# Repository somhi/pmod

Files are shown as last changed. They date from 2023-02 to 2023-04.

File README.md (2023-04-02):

# PMOD / USB3 adapters

This repository is home of simple adapters between PMOD / USB3 and other connectors.

* PMOD-USB3 is a passive adapter between PMOD and USB3 (see SNAC adapters used in MiSTer project).
* PS2-UART-USB3 is a passive adapter between USB3 and PS2 connector (mouse+keyboard). It also offers an UART header (Rx/Tx).

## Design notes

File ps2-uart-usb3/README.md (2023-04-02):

# USB3 to PS2/UART adapter

PS2-UART-USB3 is a passive adapter between USB3 and PS2 connector (mouse+keyboard). It also offers an UART header (Rx/Tx/GND). 

**STATUS**: working Ok. See testing and improvement notes below.

See correspondence of pins in [schematic](pmod.pdf). 

PS2 connector has all signal pins connected so a splitter cable can be used to connect a PS2 keyboard and mouse.

JP1 header is for selecting power supply of PS2 connector. Three options are possible:

* 5V: Place a jumper between VBUS and central pin
* External power supply can also be connected to the central pin and GND.
* ~~3V3: Place a jumper between 3V3 and central pin. For this is required a MiSTer Analog IO version with a jumper that connects 3V3 to pin 9 of USB3~~.  [CAUTION: this is not possible when using a male male USB3 cable as the pin 9 is connected to pin 5 at the other end of cable]

**NOTES ABOUT USB3 CABLES**

* male male cable is crossover cable, meaning that Rx- is connected to Tx- and Rx+ to Tx+

* female male cable is straight cable, meaning all pins have exact correspondence in each side of cable (Rx- with Rx-, ...)

**SETUP IN MISTER DE10-nano FPGA**

* Connect  an [SNAC level shifter adapter](https://manuferhi.com/p/snac-adapter-for-mister) to the user IO port of MiSTer Analog addon

* Connect a male male USB3 cable between the SNAC adapter and the USB3 to PS2 adapter

* Connect a [PS2 splitter cable](https://es.aliexpress.com/item/32827138560.html) if you intend to use keyboard and mouse simultaneously.

**TODO & IMPROVEMENTS**

* Make a male USB3 version with voltage protections so the SNAC adapter and male male cable would be unnecessary
* Shield pins of PS2 connector are not connected to GND
* 3V3 silkscreen NOTE at pcb back "3V3 from MiSTer analog IO with user IO jumper placed"

**TESTING**

* Tested using PMOD-USB3 adapter: UART, keyboard and mouse works well, with 3V3 without SNAC adapter, or with 5V and SNAC level shifter adapter.  This means in MiSTer should work.

  NOTE: Code in FPGA side need to take into account the crossover signals of the male to male cable.

* Tested from USB3 port of Deca cape: Keyboard not working good with the integrated level shifter of Deca cape.

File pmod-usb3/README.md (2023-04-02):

# PMOD to USB3 adapter

PMOD-USB3 is a passive adapter between PMOD and USB3. Only 7 pins are wired as is the maximum of USB3. 

**STATUS**: tested with a GEN SMS SNAC with a gamepad working well with 3V3

See correspondence of pins in [schematic](pmod.pdf). 

PMOD only outputs 3V3. 

JP1 header is for detaching power supply pin from both connectors, as PMOD is 3V3 and VBUS is usually 5V. 

JP1 header header has three pins: 3V3 from PMOD, VBUS from USB3 and GND. 

VBUS is the power supply to whatever is connected to the SNAC adapter. 

Different power supply options:

* Placing a jumper between 3V3 and VBUS (will not work on all gamepads)

* Other option is to connect 5V wire from FPGA to VBUS pin   (note that this will require to use a SNAC level shifter in between for protecting 3V3 GPIO)

* Third option would be to get 5V from external power supply so you will need to connect two wires: VBUS to 5V and GND (SNAC level shifter required also).

**PLEASE MAKE SURE NOT TO PLACE A JUMPER EVER BETWEEN VBUS AND GND PINS. I'm not responsible for what could happen.**

**NOTES ABOUT USB3 CABLES**

* male male cable is crossover cable, meaning that Rx- is connected to Tx- and Rx+ to Tx+

* female male cable is straight cable, meaning all pins have exact correspondence in each side of cable (Rx- with Rx-, ...)

**TODO**

* move GND pin to avoid user placing a jumper which will short GND and VBUS

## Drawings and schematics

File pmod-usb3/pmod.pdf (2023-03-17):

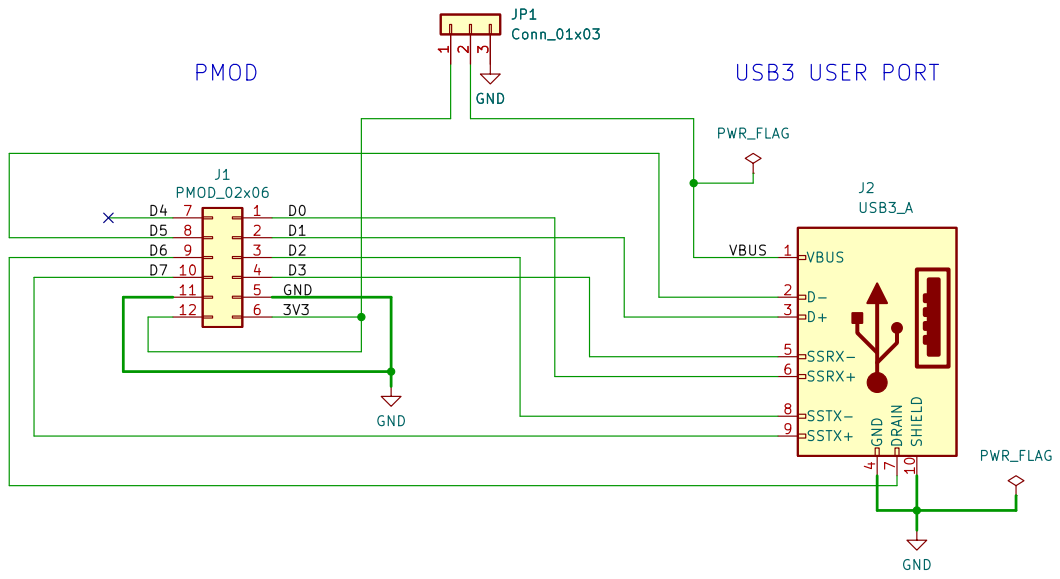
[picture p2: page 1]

10 | 4
11 | 5
12 | 6

Id: 1/1 Title: Pmod / USB3 adapters

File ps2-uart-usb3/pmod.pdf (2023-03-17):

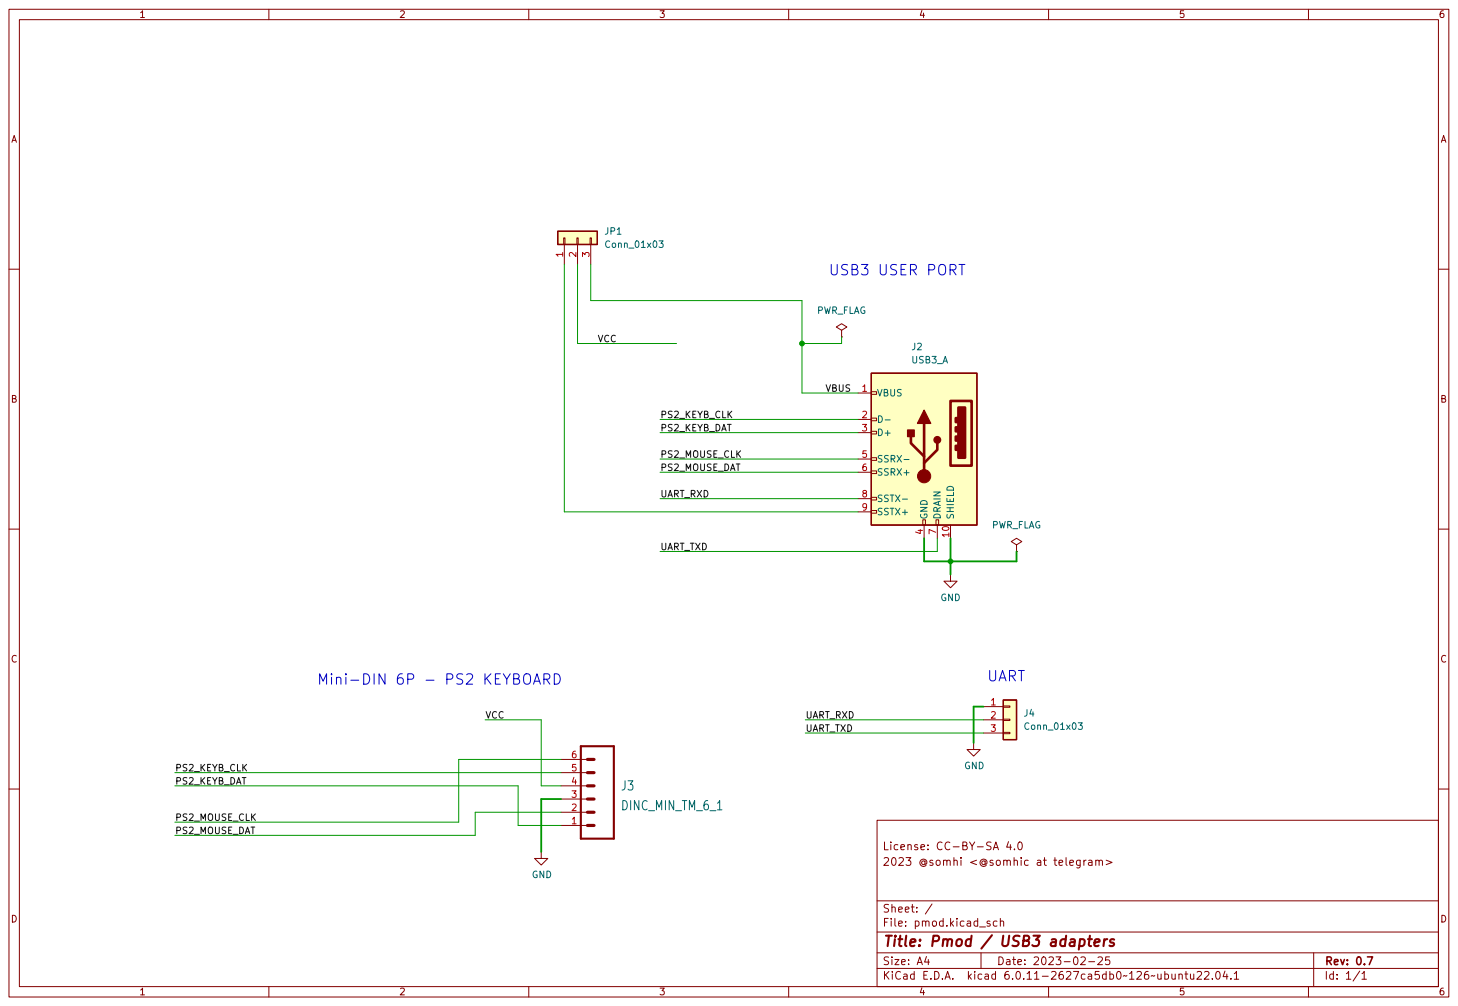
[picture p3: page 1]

Id: 1/1 Title: Pmod / USB3 adapters

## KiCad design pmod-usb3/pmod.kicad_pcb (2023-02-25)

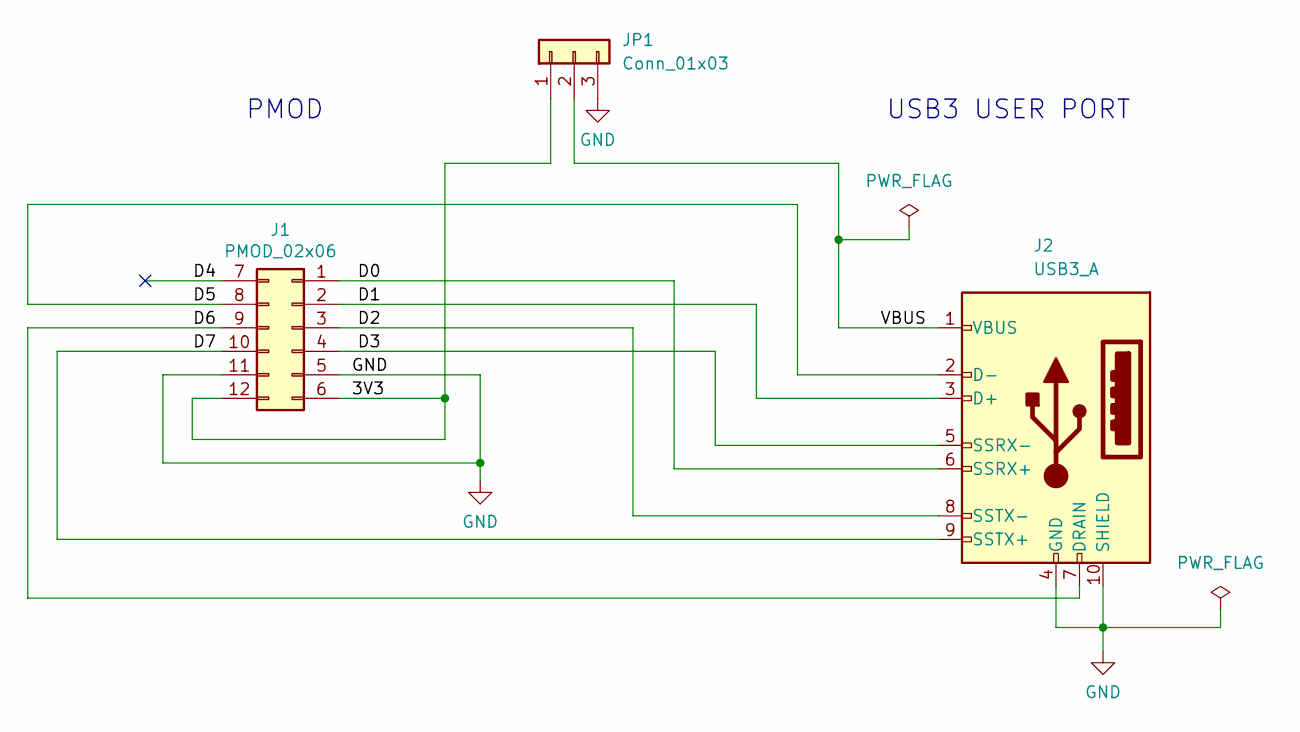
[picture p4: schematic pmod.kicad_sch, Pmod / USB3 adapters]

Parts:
J1: PMOD_02x06; PMODHeader_2x06_P2.54mm_Horizontal
J2: USB3_A; USB-3.0-TH_C69073
JP1: Conn_01x03; PinHeader_1x03_P2.54mm_Vertical

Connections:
/3V3: J1.6, J1.12, JP1.1
/D0: J1.1, J2.6 (SSRX+)
/D1: J1.2, J2.3 (D+)
/D2: J1.3, J2.8 (SSTX-)
/D3: J1.4, J2.5 (SSRX-)
/D4: J1.7
/D5: J1.8, J2.2 (D-)
/D6: J1.9, J2.7 (DRAIN)
/D7: J1.10, J2.9 (SSTX+)
/VBUS: J2.1 (VBUS), JP1.2
GND: J1.5, J1.11, J2.4 (GND), J2.10 (SHIELD), JP1.3

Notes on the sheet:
PMOD
USB3 USER PORT

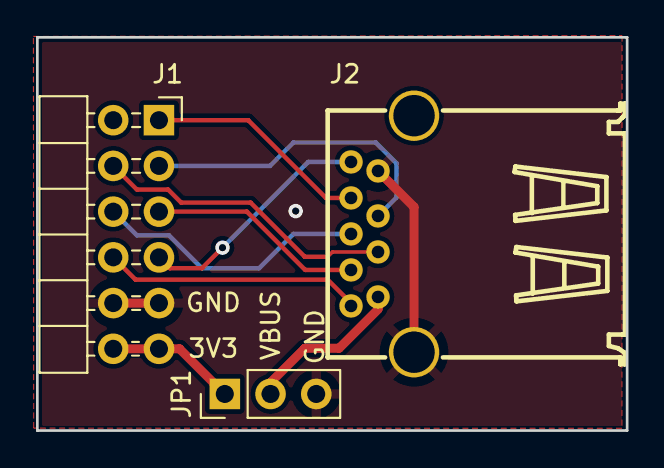
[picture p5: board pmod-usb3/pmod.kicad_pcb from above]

Board: 2 copper layers, 32.8 x 21.8 mm, 3 parts (0 on the bottom side), 10 nets.

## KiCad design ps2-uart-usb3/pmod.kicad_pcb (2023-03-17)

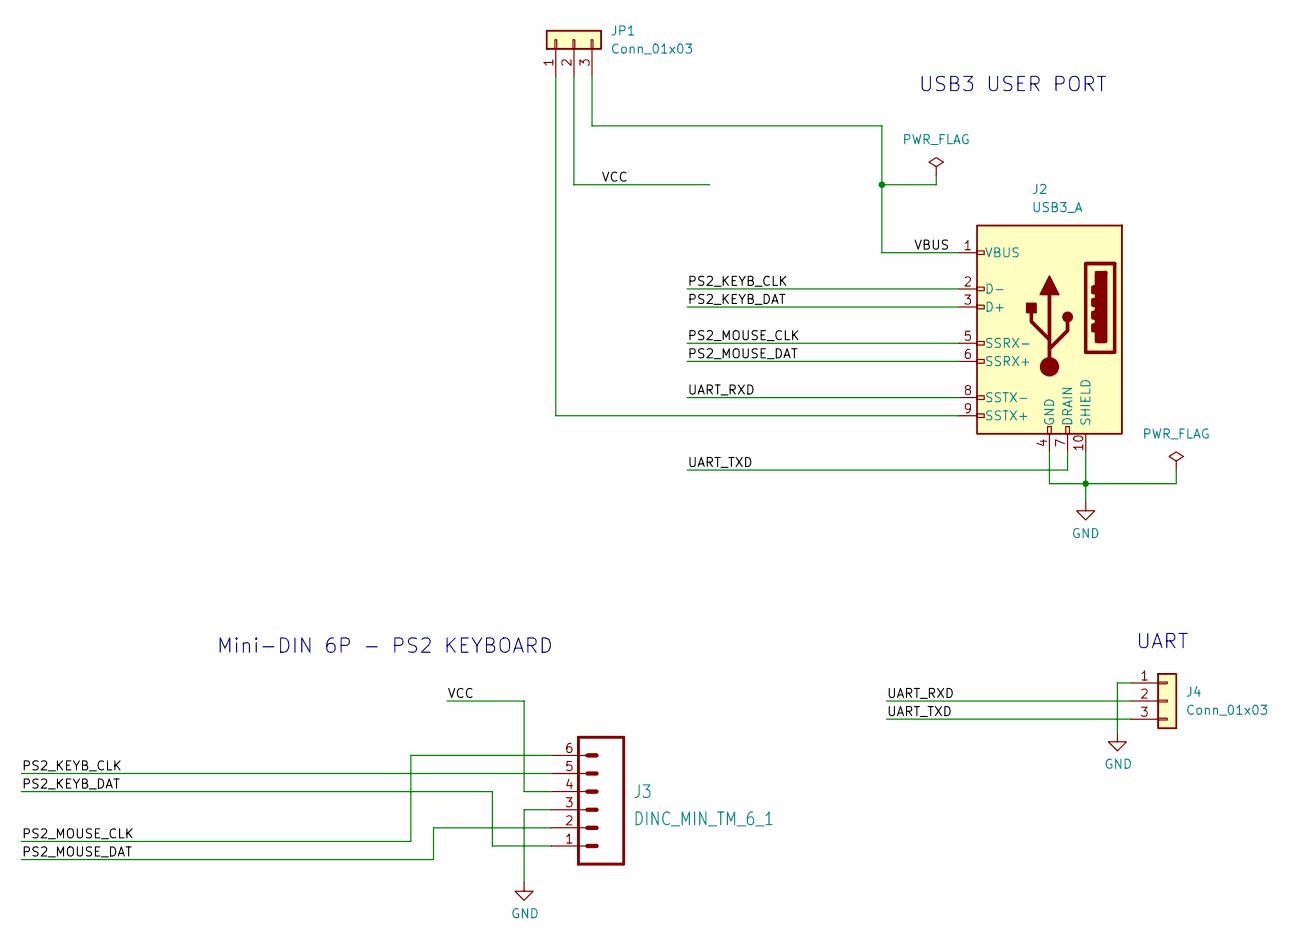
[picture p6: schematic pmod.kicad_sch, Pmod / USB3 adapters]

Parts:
J2: USB3_A; USB-3.0-TH_C69073
J3: DINC_MIN_TM_6_1; DINC_MIN_TM_6_1PRIMARY
J4: Conn_01x03; PinHeader_1x03_P2.54mm_Vertical
JP1: Conn_01x03; PinHeader_1x03_P2.54mm_Vertical

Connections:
/PS2_KEYB_CLK: J2.2 (D-), J3.5
/PS2_KEYB_DAT: J2.3 (D+), J3.1
/PS2_MOUSE_CLK: J2.5 (SSRX-), J3.6
/PS2_MOUSE_DAT: J2.6 (SSRX+), J3.2
/UART_RXD: J2.8 (SSTX-), J4.2
/UART_TXD: J2.7 (DRAIN), J4.3
/VBUS: J2.1 (VBUS), JP1.3
/VCC: J3.4, JP1.2
GND: J2.4 (GND), J2.10 (SHIELD), J3.3, J4.1
unnamed: J2.9 (SSTX+), JP1.1

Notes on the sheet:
UART
Mini-DIN 6P - PS2 KEYBOARD
USB3 USER PORT

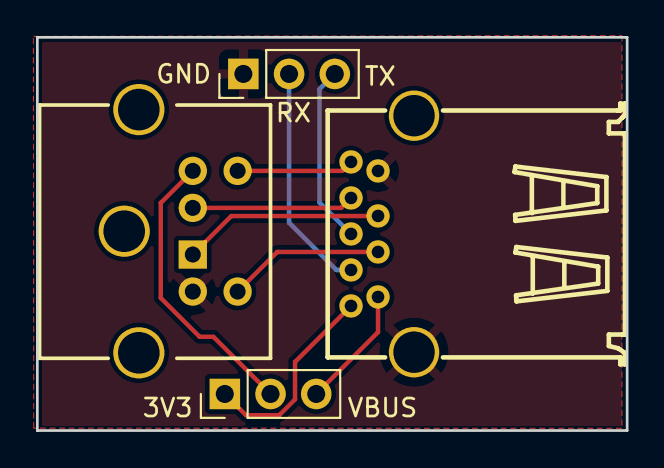
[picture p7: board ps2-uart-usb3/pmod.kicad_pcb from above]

Board: 2 copper layers, 32.8 x 21.8 mm, 4 parts (0 on the bottom side), 10 nets.

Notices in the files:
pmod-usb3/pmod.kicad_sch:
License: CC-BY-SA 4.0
